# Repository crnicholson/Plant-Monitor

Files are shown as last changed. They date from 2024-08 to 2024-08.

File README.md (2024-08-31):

# Plant Monitor

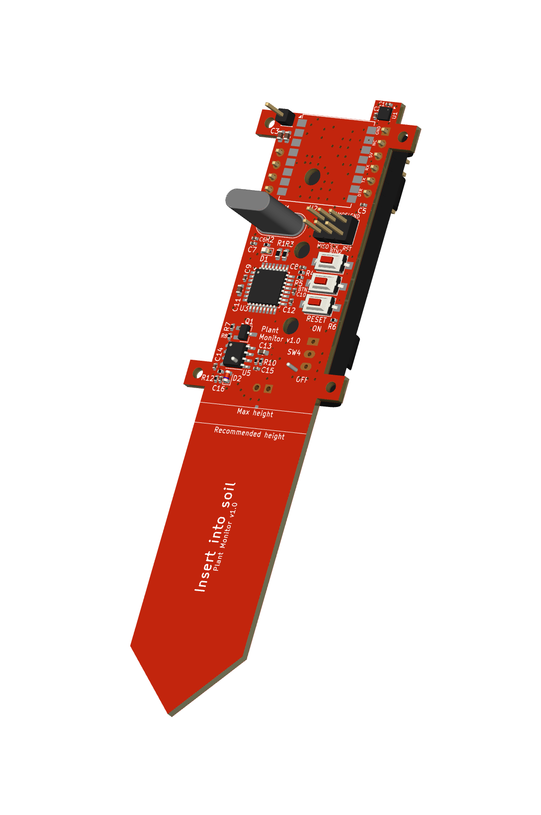
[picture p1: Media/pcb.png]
Glider
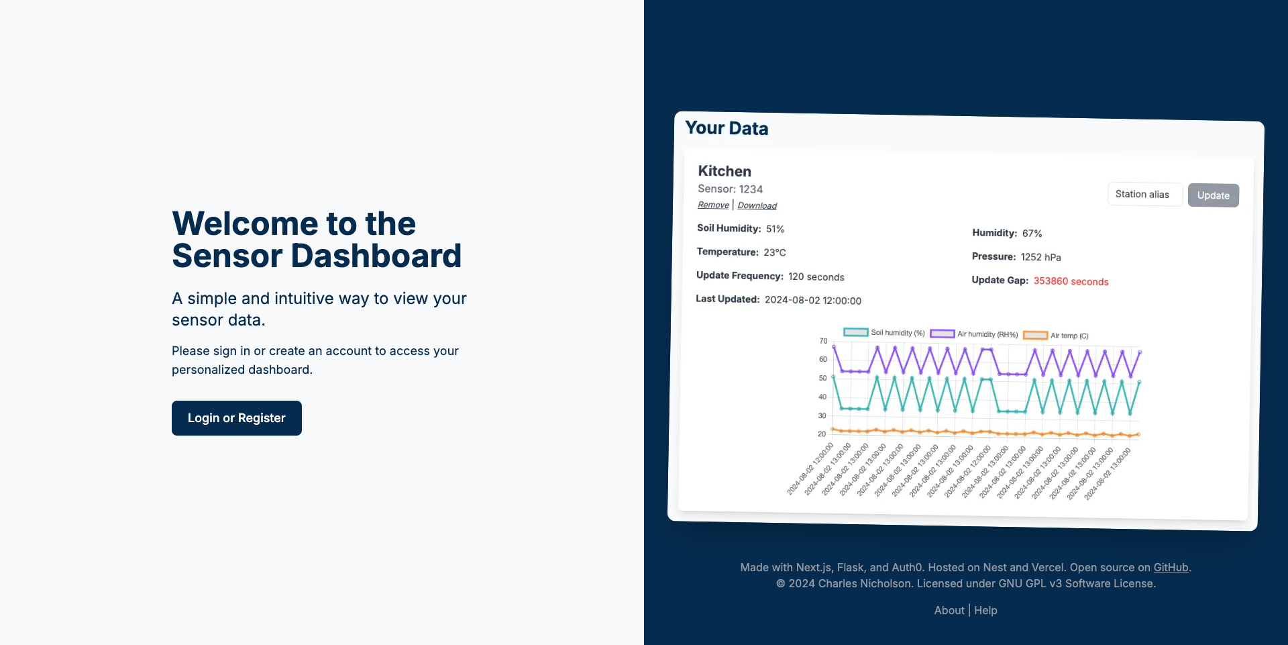
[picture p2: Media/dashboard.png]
PCB
 | 
-- | --
<i>Plant Monitor transmitter circuit board.</i> | <i>Web interface login page.</i>

## About

Plant Monitor is a way to view data from a remote humidity sensor on web interface, which then tells you when you need to water your plants plus the air humidity, soil humidity, air temp, and air pressure. These metrics can be combined with AI to predict forest fires. 

## Get Started

Plant Monitor uses Auth0 to securely log into the web interface. No data or passwords is shown to me. 

PCBs:
1. First, order your transmitter PCB and ground PCB from JLCPCB (soon from me).
2. For now, contact me to add a station number and a passcode for the station. At this time, you'll also need to program your WiFi SSID and password to the ground station PCB and the station number to the transmitter PCB.
3. Turn on the transmitter PCB and place it in the soil of a plant you want to monitor. Make sure to not get it wet!
4. Turn on the ground station PCB. This will receive all the data from the transmitter (sensor) and automatically put it on the web.

Web interface:
1. Next, Go to the [web interface](https://plant-monitor-web.vercel.app) and make an account. 
2. Then, add your station number. Remember to add the password of the station when entering the station number. 
3. The data will now be automatically fetched every 5 seconds. 
4. Lastly, interact with the graphs to see your data over time. 

## Need Help?

Do you have any questions? Are the docs incomplete and you want to ask anything? Do you just want to say hi (or how cool my project is!)?

Reach out to me at [charlienicholsonr@gmail.com](mailto:charlienicholsonr@gmail.com).

## Credits

Thanks to Zach Latta for the idea.

## License

Both the software and documentation are under the [GNU GPL v3 license](https://choosealicense.com/licenses/gpl-3.0/). The hardware and the 3D files are under the [CERN Open Hardware Licence Version 2 - Strongly Reciprocal](https://choosealicense.com/licenses/cern-ohl-s-2.0/). The media is under the [CC BY 4.0 DEED](https://creativecommons.org/licenses/by/4.0/).

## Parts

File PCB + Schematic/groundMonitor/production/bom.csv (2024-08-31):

Designator | Footprint | Quantity | Value | LCSC Part #
AE1 | SMA_Amphenol_132289_EdgeMount | 1 | Antenna
C1, C3, C5 | 0603 | 3 | 10 uF | C19702
C2, C4, C6, C7 | 0603 | 4 | 100 nF | C14663
D1 | 0603 | 1 | RED | C2286
J1 | PinHeader_1x06_P2.54mm_Vertical | 1 | FTDI
J2 | PinHeader_1x11_P2.54mm_Vertical | 1 | Header
J3 | BarrelJack_Horizontal | 1 | 5-12 V
J4 | USB_C_Receptacle_GCT_USB4105-xx-A_16P_TopMnt_Horizontal | 1 | USB-C | C136423
J5 | PinHeader_1x03_P2.54mm_Vertical | 1 | Power
R1 | 0402 | 1 | 1 K | C11702
R2, R3 | 0402 | 2 | 5.1 K | C25905
SW1 | SW_SPST_CK_RS282G05A3 | 1 | Boot | C2888954
SW2 | SW_SPST_CK_RS282G05A3 | 1 | EN | C2888954
U1 | ESP32-C3-MINI-1_EXP | 1 | ESP32-C3-MINI-1-H4 | C2934569
U2 | Ai-Thinker-Ra-01-LoRa | 1 | Ra-01 | C2830750
U3 | SOT-223-3_TabPin2 | 1 | AMS1117-3.3

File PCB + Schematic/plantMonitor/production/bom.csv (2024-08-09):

Designator | Footprint | Quantity | Value | LCSC Part #
AE1 | PinHeader_1x01_P2.54mm_Vertical | 1 | Antenna
BT1 | BatteryHolder_Keystone_2469_2xAAA | 1 | Battery
C1 | 0402 | 1 | 1 uF | C52923
C10, C12, C14, C2, C5, C9 | 0402 | 6 | 100 nF | C1525
C11, C3 | 0603 | 2 | 10 uF | C19702
C13 | 0603 | 1 | 470 pF | C1620
C15 | 0402 | 1 | 10 nF | C15195
C16, C8 | 0402 | 2 | 1 nF | C1523
C17 | Soil | 1 | Soil
C4 | 0603 | 1 | 100 nF | C14663
C6, C7 | 0402 | 2 | 22 pF | C1555
D1 | 0603 | 1 | LED | C2286
D2 | D_MicroMELF | 1 | MCL103A | C142609
H1, H2, H3, H4 | MountingHole_2.2mm_M2 | 4 | MountingHole
J1 | PinHeader_2x03_P2.54mm_Vertical | 1 | AT_ISP
J2 | PinHeader_1x06_P2.54mm_Vertical | 1 | FTDI
J3 | PinHeader_1x05_P2.54mm_Vertical | 1 | GPIO
Q1 | SC-59_Handsoldering | 1 | DMN1019USN-13 | C145103
R1, R3 | 0603 | 2 | 1.8 K | C4177
R10 | 0402 | 1 | 330 | C25104
R11, R7 | 0402 | 2 | 10 K | C25744
R12 | 0402 | 1 | 1 M
R2 | 0402 | 1 | 1 K | C11702
R4, R5 | 0402 | 2 | 1 M | C26083
R6 | 0402 | 1 | 220
R8 | 0402 | 1 | 10 K | C25077
R9 | 0402 | 1 | 1.5 K | C25867
SW1 | SW_SPST_CK_RS282G05A3 | 1 | BUTTON2 | C2888954
SW2 | SW_SPST_CK_RS282G05A3 | 1 | BUTTON1 | C2888954
SW3 | SW_SPST_CK_RS282G05A3 | 1 | RESET | C2888954
SW4 | SW_Slide_SPDT | 1 | Power
U1 | Bosch_LGA-8_2.5x2.5mm_P0.65mm_ClockwisePinNumbering | 1 | BME280 | C92489
U2 | Ai-Thinker-Ra-01-LoRa | 1 | Ra-01 | C2830750
U3 | TQFP-32_7x7mm_P0.8mm | 1 | ATmega328P-A | C14877
U5 | SOIC-8_3.9x4.9mm_P1.27mm | 1 | TLC555CDR | C6986
Y1 | Crystal_HC18-U_Vertical | 1 | 8MHz

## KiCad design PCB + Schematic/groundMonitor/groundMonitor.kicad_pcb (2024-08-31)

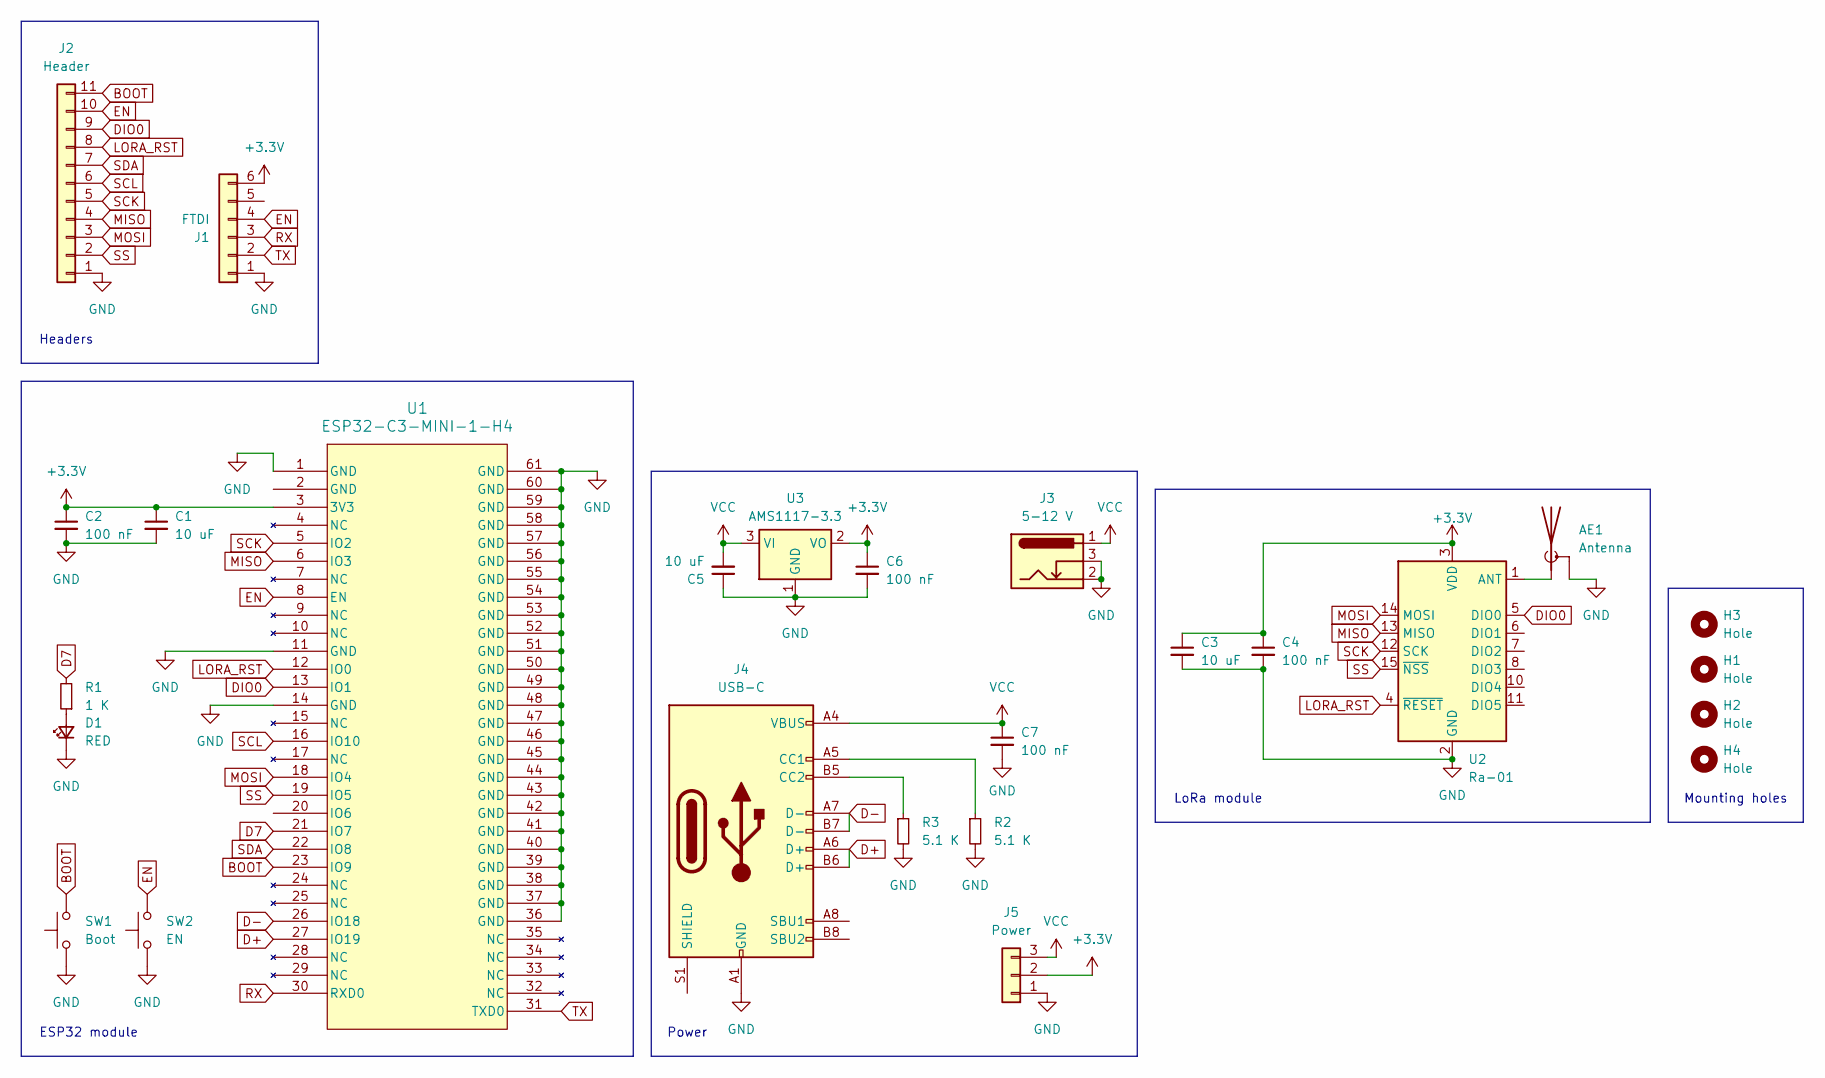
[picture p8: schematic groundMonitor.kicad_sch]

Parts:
AE1: Antenna; SMA_Amphenol_132289_EdgeMount
C1, C3, C5: 10 uF; C_0603_1608Metric; LCSC C19702
C2, C4, C6, C7: 100 nF; C_0603_1608Metric; LCSC C14663
D1: RED; LED_0603_1608Metric; LCSC C2286
H1, H2, H3, H4: Hole; MountingHole_3.2mm_M3
J1: FTDI; PinHeader_1x06_P2.54mm_Vertical
J2: Header; PinHeader_1x11_P2.54mm_Vertical
J3: 5-12 V; BarrelJack_Horizontal
J4: USB-C; USB_C_Receptacle_GCT_USB4105-xx-A_16P_TopMnt_Horizontal; LCSC C136423
J5: Power; PinHeader_1x03_P2.54mm_Vertical
R1: 1 K; R_0402_1005Metric; LCSC C11702
R2, R3: 5.1 K; R_0402_1005Metric; LCSC C25905
SW1: Boot; SW_SPST_CK_RS282G05A3; LCSC C2888954
SW2: EN; SW_SPST_CK_RS282G05A3; LCSC C2888954
U1: ESP32-C3-MINI-1-H4; ESP32-C3-MINI-1_EXP; LCSC C2934569
U2: Ra-01; Ai-Thinker-Ra-01-LoRa; LCSC C2830750
U3: AMS1117-3.3; SOT-223-3_TabPin2

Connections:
+3.3V: C1.1, C2.1, C3.1, C4.1, C6.1, J1.6, J5.2, U1.3 (3V3), U2.3 (VDD), U3.2 (VO)
BOOT: J2.11, SW1.2, U1.23 (IO9)
D7: R1.2, U1.21 (IO7)
D+: J4.A6 (D+), J4.B6 (D+), U1.27 (IO19)
D-: J4.A7 (D-), J4.B7 (D-), U1.26 (IO18)
DIO0: J2.9, U1.13 (IO1), U2.5 (DIO0)
EN: J1.4, J2.10, SW2.2, U1.8 (EN)
GND: AE1.2 (Shield), C1.2, C2.2, C3.2, C4.2, C5.1, C6.2, C7.2, D1.1 (K), J1.1, J2.1, J3.2, J3.3, J4.A1 (GND), J4.A12 (GND), J4.B1 (GND), J4.B12 (GND), J5.1, R2.2, R3.2, SW1.1, SW2.1, U1.1 (GND), U1.11 (GND), U1.14 (GND), U1.36 (GND), U1.37 (GND), U1.38 (GND), U1.39 (GND), U1.40 (GND), U1.41 (GND), U1.42 (GND), U1.43 (GND), U1.44 (GND), U1.45 (GND), U1.46 (GND), U1.47 (GND), U1.48 (GND), U1.49 (GND), U1.50 (GND), U1.51 (GND), U1.52 (GND), U1.53 (GND), U1.54 (GND), U1.55 (GND), U1.56 (GND), U1.57 (GND), U1.58 (GND), U1.59 (GND), U1.60 (GND), U1.61 (GND), U2.2 (GND), U2.9 (GND), U2.16 (GND), U3.1 (GND)
LORA_RST: J2.8, U1.12 (IO0), U2.4 (~RESET)
MISO: J2.4, U1.6 (IO3), U2.13 (MISO)
MOSI: J2.3, U1.18 (IO4), U2.14 (MOSI)
unnamed: AE1.1 (A), U2.1 (ANT)
unnamed: D1.2 (A), R1.1
unnamed: J4.A5 (CC1), R2.1
unnamed: J4.B5 (CC2), R3.1
RX: J1.3, U1.30 (RXD0)
SCK: J2.5, U1.5 (IO2), U2.12 (SCK)
SCL: J2.6, U1.16 (IO10)
SDA: J2.7, U1.22 (IO8)
SS: J2.2, U1.19 (IO5), U2.15 (~NSS)
TX: J1.2, U1.31 (TXD0)
VCC: C5.2, C7.1, J3.1, J4.A4 (VBUS), J4.A9 (VBUS), J4.B4 (VBUS), J4.B9 (VBUS), J5.3, U3.3 (VI)

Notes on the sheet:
ESP32 module
Power
Headers
Mounting holes
LoRa module

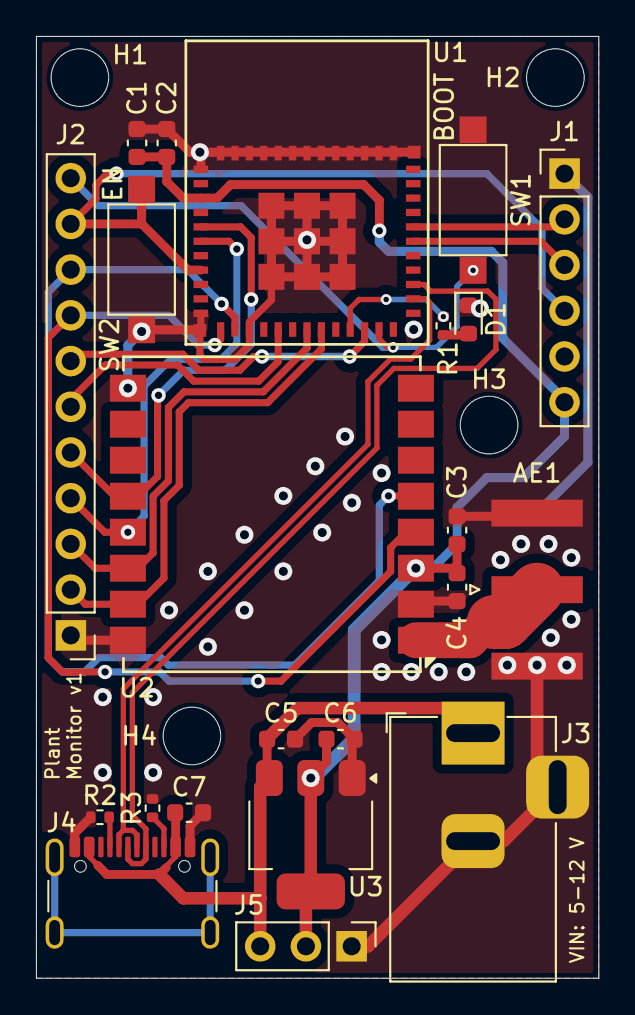
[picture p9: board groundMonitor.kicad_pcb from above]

Board: 2 copper layers, 31.2 x 52.3 mm, 26 parts (0 on the bottom side), 22 nets.

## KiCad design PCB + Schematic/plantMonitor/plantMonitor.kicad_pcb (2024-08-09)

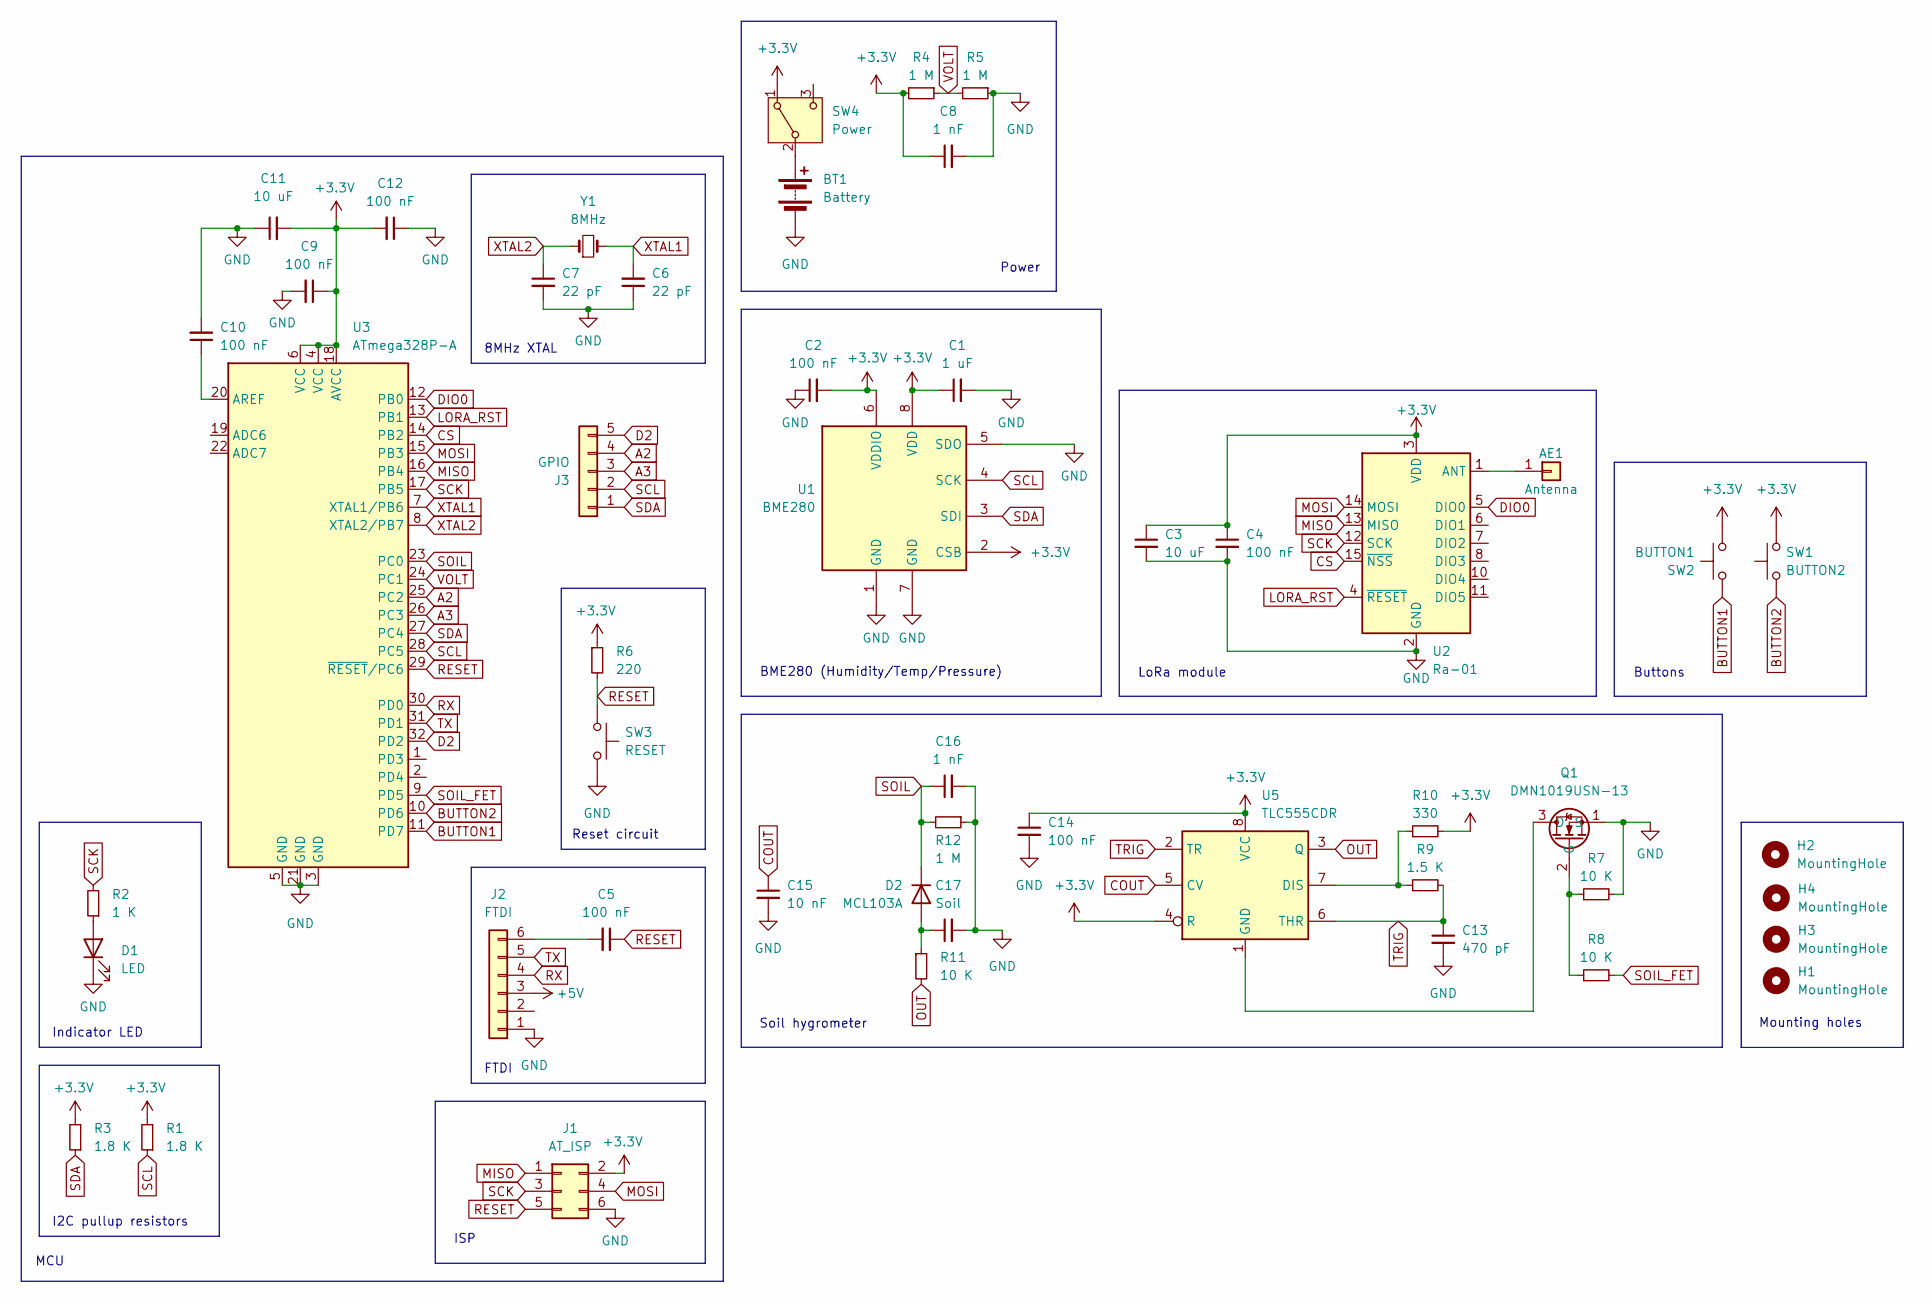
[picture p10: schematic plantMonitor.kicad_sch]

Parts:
AE1: Antenna; PinHeader_1x01_P2.54mm_Vertical
BT1: Battery; BatteryHolder_Keystone_2469_2xAAA
C1: 1 uF; C_0402_1005Metric; LCSC C52923
C2, C5, C9, C10, C12, C14: 100 nF; C_0402_1005Metric; LCSC C1525
C3, C11: 10 uF; C_0603_1608Metric; LCSC C19702
C4: 100 nF; C_0603_1608Metric; LCSC C14663
C6, C7: 22 pF; C_0402_1005Metric; LCSC C1555
C8, C16: 1 nF; C_0402_1005Metric; LCSC C1523
C13: 470 pF; C_0603_1608Metric; LCSC C1620
C15: 10 nF; C_0402_1005Metric; LCSC C15195
C17: Soil
D1: LED; LED_0603_1608Metric; LCSC C2286
D2: MCL103A; D_MicroMELF; LCSC C142609
H1, H2, H3, H4: MountingHole; MountingHole_2.2mm_M2
J1: AT_ISP; PinHeader_2x03_P2.54mm_Vertical
J2: FTDI; PinHeader_1x06_P2.54mm_Vertical
J3: GPIO; PinHeader_1x05_P2.54mm_Vertical
Q1: DMN1019USN-13; SC-59_Handsoldering; LCSC C145103
R1, R3: 1.8 K; R_0603_1608Metric; LCSC C4177
R2: 1 K; R_0402_1005Metric; LCSC C11702
R4, R5: 1 M; R_0402_1005Metric; LCSC C26083
R6: 220; R_0402_1005Metric
R7, R11: 10 K; R_0402_1005Metric; LCSC C25744
R8: 10 K; R_0402_1005Metric; LCSC C25077
R9: 1.5 K; R_0402_1005Metric; LCSC C25867
R10: 330; R_0402_1005Metric; LCSC C25104
R12: 1 M; R_0402_1005Metric
SW1: BUTTON2; SW_SPST_CK_RS282G05A3; LCSC C2888954
SW2: BUTTON1; SW_SPST_CK_RS282G05A3; LCSC C2888954
SW3: RESET; SW_SPST_CK_RS282G05A3; LCSC C2888954
SW4: Power; SW_Slide_SPDT
U1: BME280; Bosch_LGA-8_2.5x2.5mm_P0.65mm_ClockwisePinNumbering; LCSC C92489
U2: Ra-01; Ai-Thinker-Ra-01-LoRa; LCSC C2830750
U3: ATmega328P-A; TQFP-32_7x7mm_P0.8mm; LCSC C14877
U5: TLC555CDR; SOIC-8_3.9x4.9mm_P1.27mm; LCSC C6986
Y1: 8MHz; Crystal_HC18-U_Vertical

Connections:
+3.3V: C1.1, C2.2, C3.1, C4.1, C8.1, C9.1, C11.2, C12.2, C14.1, J1.2, R1.2, R3.2, R4.2, R6.1, R10.2, SW1.2, SW2.2, SW4.1 (A), U1.2 (CSB), U1.6 (VDDIO), U1.8 (VDD), U2.3 (VDD), U3.4 (VCC), U3.6 (VCC), U3.18 (AVCC), U5.4 (R), U5.8 (VCC)
+5V: J2.3
A2: J3.4, U3.25 (PC2)
A3: J3.3, U3.26 (PC3)
BUTTON1: SW2.1, U3.11 (PD7)
BUTTON2: SW1.1, U3.10 (PD6)
COUT: C15.1, U5.5 (CV)
CS: U2.15 (~NSS), U3.14 (PB2)
D2: J3.5, U3.32 (PD2)
DIO0: U2.5 (DIO0), U3.12 (PB0)
GND: BT1.2 (-), C1.2, C2.1, C3.2, C4.2, C6.1, C7.2, C8.2, C9.2, C10.2, C11.1, C12.1, C13.2, C14.2, C15.2, C16.2, C17.2, D1.1 (K), J1.6, J2.1, Q1.1 (S), R5.1, R7.2, R12.1, SW3.2, U1.1 (GND), U1.5 (SDO), U1.7 (GND), U2.2 (GND), U2.9 (GND), U2.16 (GND), U3.3 (GND), U3.5 (GND), U3.21 (GND)
LORA_RST: U2.4 (~RESET), U3.13 (PB1)
MISO: J1.1, U2.13 (MISO), U3.16 (PB4)
MOSI: J1.4, U2.14 (MOSI), U3.15 (PB3)
unnamed: AE1.1, U2.1 (ANT)
unnamed: BT1.1 (+), SW4.2 (B)
unnamed: D1.2 (A), R2.1
unnamed: C17.1, D2.2 (A), R11.1
unnamed: C5.2, J2.6
unnamed: Q1.3 (D), U5.1 (GND)
unnamed: Q1.2 (G), R7.1, R8.1
unnamed: C10.1, U3.20 (AREF)
unnamed: R9.1, R10.1, U5.7 (DIS)
OUT: R11.2, U5.3 (Q)
RESET: C5.1, J1.5, R6.2, SW3.1, U3.29 (~RESET/PC6)
RX: J2.4, U3.30 (PD0)
SCK: J1.3, R2.2, U2.12 (SCK), U3.17 (PB5)
SCL: J3.2, R1.1, U1.4 (SCK), U3.28 (PC5)
SDA: J3.1, R3.1, U1.3 (SDI), U3.27 (PC4)
SOIL: C16.1, D2.1 (K), R12.2, U3.23 (PC0)
SOIL_FET: R8.2, U3.9 (PD5)
TRIG: C13.1, R9.2, U5.2 (TR), U5.6 (THR)
TX: J2.5, U3.31 (PD1)
VOLT: R4.1, R5.2, U3.24 (PC1)
XTAL1: C6.2, U3.7 (XTAL1/PB6), Y1.2
XTAL2: C7.1, U3.8 (XTAL2/PB7), Y1.1

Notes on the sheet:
Power
LoRa module
Buttons
Reset circuit
FTDI
Indicator LED
BME280 (Humidity/Temp/Pressure)
I2C pullup resistors
8MHz XTAL
MCU
Soil hygrometer
ISP
Mounting holes

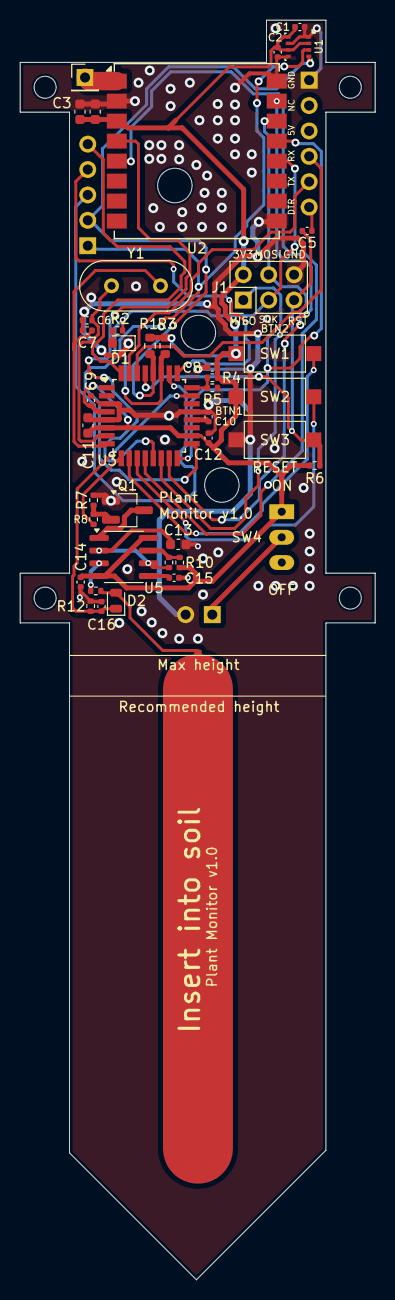
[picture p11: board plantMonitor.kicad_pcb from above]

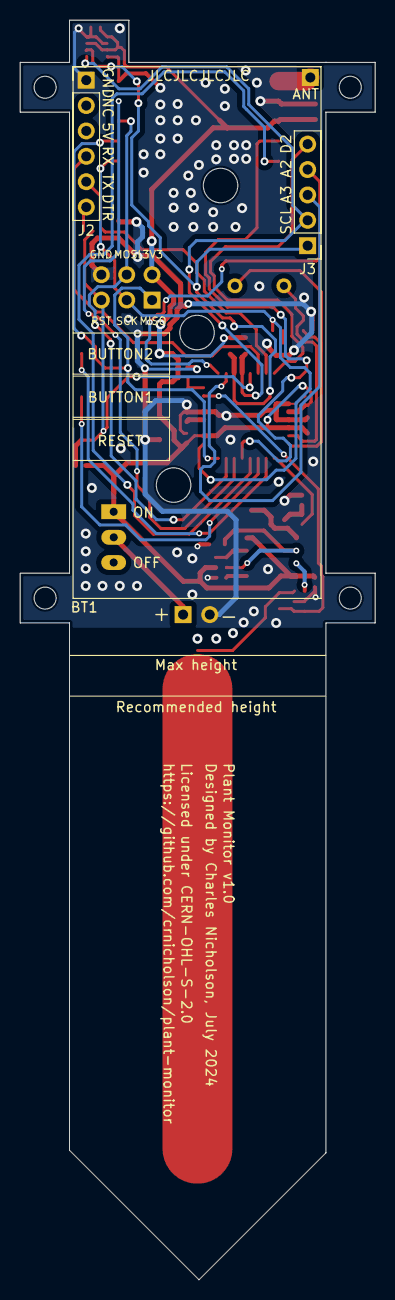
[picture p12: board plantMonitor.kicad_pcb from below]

Board: 2 copper layers, 35.5 x 126.0 mm, 50 parts (3 on the bottom side), 35 nets.

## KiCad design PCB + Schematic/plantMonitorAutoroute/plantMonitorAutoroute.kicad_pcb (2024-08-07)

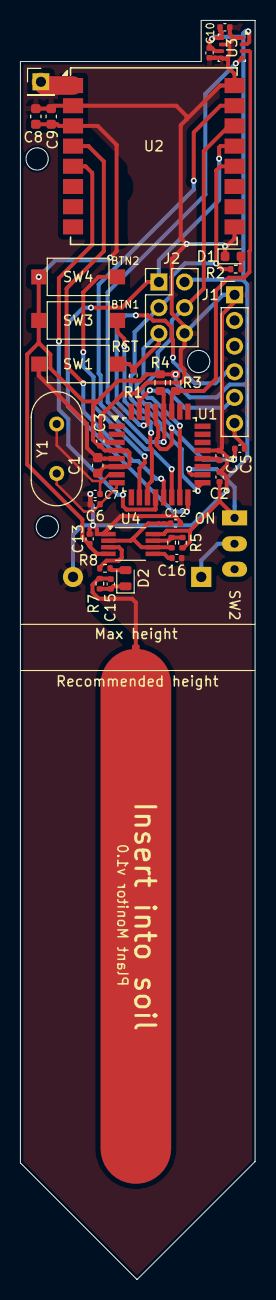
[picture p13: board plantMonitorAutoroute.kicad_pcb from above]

Board: 2 copper layers, 23.2 x 124.7 mm, 42 parts (1 on the bottom side), 29 nets.

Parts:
AE1: Antenna; PinHeader_1x01_P2.54mm_Vertical
BT1: Battery; BatteryHolder_Keystone_2468_2xAAA
C1, C8: 10 uF; C_0603_1608Metric
C2, C3, C4, C5, C10, C13: 100 nF; C_0402_1005Metric
C6, C7: 22 pF; C_0402_1005Metric
C9: 100 nF; C_0603_1608Metric
C11: 1 uF; C_0402_1005Metric
C12: 470 pF; C_0402_1005Metric
C14: Soil
C15: 1 nF; C_0402_1005Metric
C16: 10 nF; C_0402_1005Metric
D1: LED; LED_0603_1608Metric
D2: SM4007; D_MicroMELF
H1, H1#2, H4: MountingHole; MountingHole_2.2mm_M2
J1: FTDI; PinHeader_1x06_P2.54mm_Vertical
J2: AT_ISP; PinHeader_2x03_P2.54mm_Vertical
R1: 220; R_0402_1005Metric
R2: 1 K; R_0402_1005Metric
R3, R4: 1.8 K; R_0603_1608Metric
R5: 330; R_0402_1005Metric
R6: 1.5 K; R_0402_1005Metric
R7: 1 M; R_0402_1005Metric
R8: 10 K; R_0402_1005Metric
SW1: AT_RESET; SW_SPST_CK_RS282G05A3
SW2: Power; SW_Slide_SPDT
SW3: BUTTON1; SW_SPST_CK_RS282G05A3
SW4: BUTTON2; SW_SPST_CK_RS282G05A3
U1: ATmega328P-A; TQFP-32_7x7mm_P0.8mm
U2: Ra-01; Ai-Thinker-Ra-01-LoRa
U3: BME280; Bosch_LGA-8_2.5x2.5mm_P0.65mm_ClockwisePinNumbering
U4: TLC555xPS; VSSOP-8_3.0x3.0mm_P0.65mm
Y1: 8MHz; Crystal_HC18-U_Vertical

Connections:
+3.3V: C1.2, C2.2, C3.1, C8.1, C9.1, C10.2, C11.1, C13.1, J2.2, R1.1, R3.2, R4.2, R5.2, SW2.1 (A), SW3.2, SW4.2, U1.4 (VCC), U1.6 (VCC), U1.18 (AVCC), U2.3 (VDD), U3.2 (CSB), U3.6 (VDDIO), U3.8 (VDD), U4.4 (R), U4.8 (VCC)
BUTTON1: SW3.1, U1.11 (PD7)
BUTTON2: SW4.1, U1.10 (PD6)
COUT: C16.1, U4.5 (CV)
CS: U1.14 (PB2), U2.15 (~NSS)
DIO0: U1.12 (PB0), U2.5 (DIO0)
GND: BT1.2 (-), C1.1, C2.1, C3.2, C4.2, C6.2, C7.1, C8.2, C9.2, C10.1, C11.2, C12.2, C13.2, C16.2, D1.1 (K), J1.1, J2.6, SW1.2, U1.3 (GND), U1.5 (GND), U1.21 (GND), U2.2 (GND), U2.9 (GND), U2.16 (GND), U3.1 (GND), U3.5 (SDO), U3.7 (GND), U4.1 (GND)
LORA_RST: U1.13 (PB1), U2.4 (~RESET)
MISO: J2.1, U1.16 (PB4), U2.13 (MISO)
MOSI: J2.4, U1.15 (PB3), U2.14 (MOSI)
unnamed: AE1.1, U2.1 (ANT)
unnamed: BT1.1 (+), SW2.2 (B)
unnamed: C14.1, C15.1, R7.1
unnamed: D1.2 (A), R2.1
unnamed: D2.2 (A), R8.1
unnamed: C5.2, J1.6
unnamed: C4.1, U1.20 (AREF)
unnamed: R5.1, R6.1, U4.7 (DIS)
OUT: R8.2, U4.3 (Q)
RESET: C5.1, J2.5, R1.2, SW1.1, U1.29 (~RESET/PC6)
RX: J1.4, U1.30 (PD0)
SCK: J2.3, R2.2, U1.17 (PB5), U2.12 (SCK)
SCL: R4.1, U1.28 (PC5), U3.4 (SCK)
SDA: R3.1, U1.27 (PC4), U3.3 (SDI)
SOIL: C15.2, D2.1 (K), R7.2
TRIG: C12.1, R6.2, U4.2 (TR), U4.6 (THR)
TX: J1.5, U1.31 (PD1)
XTAL1: C7.2, U1.7 (XTAL1/PB6), Y1.2
XTAL2: C6.1, U1.8 (XTAL2/PB7), Y1.1

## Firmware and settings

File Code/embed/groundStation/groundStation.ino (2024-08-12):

#include "secrets.h" // Put your WiFi credentials in this file.
#include <HTTPClient.h>
#include <LoRa.h>
#include <SPI.h>
#include <WiFi.h>

// Enables.
#define DEVMODE
#define FAST_LORA

// LoRa, following factors tuned for range.
#define FREQUENCY 915E6     // Frequency of the LoRa module. 433E6 needs a ham radio license in the US.
#define SYNC_WORD 0x40      // Sync word, or password for the communication.
#define SPREADING_FACTOR 10 // Spreading factor of the LoRa communication. Learn more here: https://forum.arduino.cc/t/what-are-the-best-settings-for-a-lora-radio/449528.
#define BANDWIDTH 62.5E3    // Bandwidth of the LoRa.
#define PACKET_FREQUENCY 30 // How many packets of data per hour?

// Pins.
#define SS_PIN 5
#define RESET_PIN A0
#define DIO0_PIN A1
#define LED 7 // SCK uses pin 13.

// Other.
#define SERVER "https://plant.cnicholson.hackclub.app" // URI of the server.
#define BAUD_RATE 115200                               // Baud rate for serial monitor.

// Vars.
long rxCount;

struct data {
  float soilHumidity, airHumidity, temperature, pressure, volts;
  long deviceID, txCount, frequency;
  bool requestRSSI;
} receivedData;

void setup() {
#ifdef DEVMODE
  while (!Serial.begin(BAUD_RATE)) {
    longBlink(LED);
  }
  Serial.println("Plant monitoring system, v1.0.");
  Serial.println("Connecting");
#endif

  WiFi.begin(SSID, PASS);

  while (WiFi.status() != WL_CONNECTED) {
    delay(500);
#ifdef DEVMODE
    Serial.print(".");
#endif
  }

#ifdef DEVMODE
  Serial.print("\nConnected to WiFi network with IP Address: ");
  Serial.println(WiFi.localIP());
#endif

  LoRa.setPins(SS_PIN, RESET_PIN, DIO0_PIN); // Has to be before LoRa.begin().

  if (!LoRa.begin(FREQUENCY)) {
#ifdef DEVMODE
    Serial.println("Starting LoRa failed!");
#endif
    while (1) {
      longBlink(LED);
    }
  }

#ifndef FAST_LORA
  LoRa.setSyncWord(SYNC_WORD);               // Defined in settings.h.
  LoRa.setSpreadingFactor(SPREADING_FACTOR); // Defined in settings.h.
  LoRa.setSignalBandwidth(BANDWIDTH);        // Defined in settings.h.
  LoRa.crc();                                // Checksum for packet error detection.
#endif

#ifdef FAST_LORA
  LoRa.setSyncWord(SYNC_WORD); // Defined in settings.h.
  LoRa.setSpreadingFactor(7);
  LoRa.setSignalBandwidth(250000);
  LoRa.crc(); // Checksum for packet error detection.
#endif

#ifdef DEVMODE
  Serial.println("LoRa initialized, starting in 1 second.");
#endif

  delay(1000);
}

void loop() {
  int packetSize = LoRa.parsePacket(); // Parse packet.

  if (packetSize > 0) {
    shortBlink(LED);

    byte receivedBytes[sizeof(receivedData) * 2]; // Array to hold received encoded bytes.
    LoRa.readBytes(receivedBytes, packetSize);

    // Decode the received data.
    for (int i = 0; i < sizeof(receivedData); i++) {
      receivedData[i] = hammingDecode(receivedBytes[i]);
    }

    rxCount++;

    // Check if the packet is a valid packet.
    if (sizeof(receivedData) == packetSize / 2) {
      shortBlink(LED);
      if (WiFi.status() == WL_CONNECTED) {
        WiFiClient client;
        HTTPClient http;

        http.begin(client, serverName + "/add-data");

        http.addHeader("Content-Type", "application/json");

        JsonDocument doc;
        doc["soilHumidity"] = receivedData.soilHumidity;
        doc["airHumidity"] = receivedData.airHumidity;
        doc["temperature"] = receivedData.temperature;
        doc["pressure"] = receivedData.pressure;
        doc["deviceID"] = receivedData.deviceID;
        doc["volts"] = receivedData.volts;
        doc["txCount"] = receivedData.txCount;
        doc["rxCount"] = rxCount;
        doc["frequency"] = receivedData.frequency;

        String requestBody;
        serializeJson(doc, requestBody);

        int httpResponseCode = http.POST(requestBody);

#ifdef DEVMODE
        Serial.print("HTTP Response code: ");
        Serial.println(httpResponseCode);
#endif

        http.end(); // Free resources.

        if (recievedData.requestRSSI) {
          LoRa.beginPacket();
          LoRa.write((byte *)&receivedData.deviceID, sizeof(long));
          LoRa.write((byte *)&LoRa.packetRssi(), sizeof(long));
          LoRa.endPacket(); // Don't use async send. This also sends the data.
        }
      } else {
#ifdef DEVMODE
        Serial.println("WiFi Disconnected.");
#endif
        while (1) {
          longBlink(LED);
        }
      }
    }
  }
}

void shortBlink(int pin) {
  digitalWrite(pin, HIGH);
  delay(100);
  digitalWrite(pin, LOW);
  delay(100);
}

void longBlink(int pin) {
  digitalWrite(pin, HIGH);
  delay(1000);
  digitalWrite(pin, LOW);
  delay(1000);
}

// Function to decode Hamming(7,4) code and correct single-bit errors.
byte hammingDecode(byte encoded) {
  byte p1 = (encoded >> 6) & 0x1;
  byte p2 = (encoded >> 5) & 0x1;
  byte p3 = (encoded >> 4) & 0x1;
  byte d1 = (encoded >> 3) & 0x1;
  byte d2 = (encoded >> 2) & 0x1;
  byte d3 = (encoded >> 1) & 0x1;
  byte d4 = (encoded >> 0) & 0x1;

  // Calculate syndrome bits.
  byte s1 = p1 ^ d1 ^ d2 ^ d4;
  byte s2 = p2 ^ d1 ^ d3 ^ d4;
  byte s3 = p3 ^ d2 ^ d3 ^ d4;

  // Determine error position.
  byte errorPos = (s3 << 2) | (s2 << 1) | s1;

  // Correct the error if needed.
  if (errorPos > 0 && errorPos <= 7) {
    encoded ^= (1 << (7 - errorPos));
  }

  // Return the original 4 data bits.
  return (d1 << 3) | (d2 << 2) | (d3 << 1) | d4;
}

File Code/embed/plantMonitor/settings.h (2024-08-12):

/*
settings.h, part of Plant Monitor, to monitor plant water levels.
Copyright (C) 2024 Charles Nicholson

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
You should have received a copy of the GNU General Public License
along with this program.  If not, see <https://www.gnu.org/licenses/>.
*/

// Enables
#define DEVMODE         // Enable and disable the serial output.
#define USE_BME         // Enable and disable the BME280.
#define FAST_LORA       // Enable and disable fast LoRa communication, disregarding other LoRa values.
#define CHANGE_TX_POWER // Enable and disable changing the transmit power based on the RSSI.

// Pins.
#define LED 13           // Onboard LED.
#define CS 10            // Chip select for the LoRa module.
#define LORA_RESET 9     // Reset pin of the LoRa module.
#define DIO0 8           // DIO0 pin of the LoRa module.
#define BUTTON1 7        // Extra button for user config.
#define BUTTON2 6        // Extra button for user config.
#define SOIL_FET 5       // FET to turn on the soil sensor.
#define WATER_PIN A0     // Analog pin to read the water level.
#define VOLTMETER_PIN A1 // Analog pin to read the voltage of the battery.

// LoRa, following factors tuned for range.
#define FREQUENCY 915E6     // Frequency of the LoRa module. 433E6 needs a ham radio license in the US.
#define SYNC_WORD 0x40      // Sync word, or password for the communication.
#define SPREADING_FACTOR 10 // Spreading factor of the LoRa communication. Learn more here: https://forum.arduino.cc/t/what-are-the-best-settings-for-a-lora-radio/449528.
#define BANDWIDTH 62.5E3    // Bandwidth of the LoRa.
#define PACKET_FREQUENCY 30 // How many packets of data per hour?

#define DEVICE_ID 1234   // ID of the device, used to identify the device. Do not change this value.
#define DEVICE_PASS 1234 // Do not change this value.

#define GET_RSSI_RATE 1440 // Minutes between getting RSSI checks to lower and raise the power consumption.

// Dynamically change the transmit power based on the RSSI.
#define RSSI_THRESHOLD_HIGH -70 // Strong signal. Getting over this will lower the TX power.
#define RSSI_THRESHOLD_LOW -90  // Weak signal. Getting over this will raise the TX power.

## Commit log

2024-07-27 More PCB
    [groundMonitor.kicad_pcb, groundMonitor.kicad_sch]
2024-08-01 I got it mostly working!
    [1234.csv, 5678.csv]
2024-08-02 Login and such
    [user.csv]
2024-08-03 Made a landing page + experimenting with other stuff!
    [1234.csv, 5678.csv]
2024-08-05 Home page, error messages
    [4321.csv]
2024-08-08 PCB routing
    [freerouting.dsn, plantMonitor.kicad_pcb, plantMonitor.kicad_sch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]
2024-08-09 Silkscreen done
    [bom.csv, designators.csv, plantMonitorCopy.kicad_pcb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]
2024-08-09 Part finding
    [plantMonitorCopy.kicad_pcb, plantMonitorCopy.kicad_sch]
2024-08-09 PCB stuff, file org
    [bom.csv, designators.csv, groundMonitor.kicad_pcb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]
2024-08-31 Edit README
    [bom.csv, groundMonitor.kicad_pcb, groundMonitor.kicad_sch]

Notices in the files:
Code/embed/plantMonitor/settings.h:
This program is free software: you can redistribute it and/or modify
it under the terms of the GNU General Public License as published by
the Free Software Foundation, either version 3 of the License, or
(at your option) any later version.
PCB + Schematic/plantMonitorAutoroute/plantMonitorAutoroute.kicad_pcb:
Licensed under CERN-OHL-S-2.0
